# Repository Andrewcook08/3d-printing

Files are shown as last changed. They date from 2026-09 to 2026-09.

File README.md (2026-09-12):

# 3d-printing

Parametric 3D-printable parts, written as Python and exported as STL. Geometry
is built with [manifold3d](https://github.com/elalish/manifold); every project
writes its STLs into `output/<project>/`, ready to drop into a slicer.

**[How it works](docs/README.md)** — a map of the system: how parts are
generated, what the checks guarantee, and how the automation fits together.

## Projects

| Project | What it is |
|---|---|
| [`fishing-rod-mounts`](src/printing3d/fishing_rod_mounts/README.md) | Low-profile wall mounts for horizontal fishing rod storage |

Adding one? See the [project contract](docs/build/project-contract.md) — a
project is discovered by declaring itself, and inherits building, locking and
verification without writing test code.

## Getting started

You need [uv](https://docs.astral.sh/uv/). Everything else is handled for you:

```sh
uv sync
```

## Generating parts

```sh
uv run build                     # every project
uv run build fishing-rod-mounts  # just one
```

STLs land in `output/<project>/` and are committed, so you can print straight
from the repo without generating anything.

## Before you print

```sh
uv run verify
```

This measures the generated solids — not the parameters they came from — and
reports whether each part is physically sound. Each project defines its own
checks.

## Development

`main` is protected: it takes no direct pushes. Every change goes through a
branch and a pull request, and CI must pass before the PR can merge. No
reviewer approval is required, so you can merge your own work once it is green.

```sh
git switch -c fix/tip-mount-lip     # branch as <type>/<description>
# ...work, commit...
git push -u origin fix/tip-mount-lip
gh pr create --fill
gh pr merge --squash --auto         # merges itself once CI is green
```

Branch names are `<type>/<short-description>`, kebab-case:

| Type | For |
|---|---|
| `part/` | A new 3D-printing project |
| `feat/` | New capability in an existing project or the shared code |
| `fix/` | Correcting something that is wrong |
| `refactor/` | Restructuring with no change to any STL |
| `docs/` | Documentation only |
| `test/` | Tests only |
| `chore/` | Dependencies, tooling, CI |

The local checks:

```sh
uv run pytest              # tests
uv run ruff check --fix .  # lint
uv run ruff format .       # format
uv run ty check            # type check
```

In a fresh clone, install the git hooks once:

```sh
uvx pre-commit install
```

They run ruff, a few file-hygiene checks, and the test suite before each
commit. If a hook reformats a file the commit stops and the fix is left
unstaged — `git add` and commit again. Use `git commit --no-verify` to skip
them for a one-off, or `uvx pre-commit uninstall` to remove them.

Every project hash-locks its shipped STLs in a `LOCKED.txt`, and the test suite
rebuilds the parts and compares. A failure there means the exported shape
changed — see [CLAUDE.md](CLAUDE.md) for what to do about it, and for how to
add a new project.

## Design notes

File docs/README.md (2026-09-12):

# How this project works

This repo turns Python into printable parts. Each 3D-printing project describes
its parts parametrically; one command generates them as STL files into a shared
output location, and a layer of checks makes sure a change to the code cannot
silently change the parts.

The shape of it:

```
a project declares named parts
        │
        ├─ build ──▶ output/<project>/*.stl        the printable artifacts
        │
        ├─ verify ─▶ measurements of the solids    is it physically sound?
        │
        └─ tests ──▶ pass / fail                   did anything change?
```

Three properties hold the whole thing together:

- **Generation is deterministic.** The same source always produces the same
  bytes, which is what makes the parts hash-lockable.
- **Dimensions are derived, never restated.** A measurement is entered once;
  everything geometric follows from it.
- **Nothing reaches the default branch unchecked.**
- **Projects are found, not listed.** Adding one touches only its own files,
  and enrols it in every check automatically.

## The components

### Making parts

| Doc | Covers |
|---|---|
| [Project contract](build/project-contract.md) | What a project must declare, and what it inherits for free |
| [Build pipeline](build/pipeline.md) | A declared part becoming an STL file, and what building reports |
| [Geometry model](build/geometry.md) | How a part's shape is expressed, and why it prints without supports |
| [Output and locking](build/output.md) | Where files land, determinism, and the hash lock |

### Checking them

| Doc | Covers |
|---|---|
| [Testing strategy](quality/testing.md) | The test layers, and what a given failure pattern means |
| [Pre-print verification](quality/verification.md) | What the physical checks guarantee about a part |

### Automation

| Doc | Covers |
|---|---|
| [CI pipeline](automation/ci.md) | The gates on a change, and why they are shaped this way |
| [Dependencies](automation/dependencies.md) | Constraints versus pins, and the upgrade lifecycle |

## Where to start

Reading in order — [build pipeline](build/pipeline.md),
[output and locking](build/output.md), [testing](quality/testing.md) — explains
how a part is produced and why you can trust the file in `output/`. The rest can
wait until you need it.

For **using** the tool, see the [root README](../README.md). For **printing and
hanging** a specific part, see that project's own README next to its source.

## About these docs

They describe behavior, not implementation, so they stay correct across
refactors. They change only when the system's behavior changes. Before editing
any of them, use the `maintaining-docs` skill.

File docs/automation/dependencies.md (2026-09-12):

# Dependencies

How versions are controlled, and how an upgrade is evaluated before it lands.

## What it does

Two layers, deliberately separate:

| Layer | Holds | Answers |
|---|---|---|
| Constraints | Acceptable version ranges | What is *allowed* |
| Lock | One exact version per package | What is *installed* |

Automated builds install strictly from the lock. That makes them **hermetic**:
a new release of anything has no effect until the lock is deliberately moved.
This is what makes generated parts reproducible — and it means the normal
checks can never notice that a newer version exists.

Both layers are generated. Neither is edited by hand.

## Covering the gap

Because the checks are blind to new releases, two mechanisms watch from outside:

| Mechanism | Produces | Covers |
|---|---|---|
| Update bot | A pull request | Anything needing a decision *and* a commit, including the versions of the automation itself |
| Scheduled upgrade check | A report only | The case the bot misses — a new release that already satisfies an existing range, so no pull request is ever opened |

Neither names any package. Both derive the list from the declared constraints,
so a newly added dependency is covered the moment it is added.

The scheduled check resolves the newest allowed versions, runs every gate, and
**commits nothing**. Bot pull requests go through the ordinary gates, so an
upgrade that changes a part fails the hash lock and cannot merge.

## Guarantees

- An upgrade cannot land without passing every gate.
- An upgrade that changes any generated part is blocked until someone decides.
- A deprecation warning from a dependency fails the run, surfacing a future
  removal while there is still time to act.

## Reading a red upgrade check

**It is a decision, not a build to fix.** The failing gate names the category —
see [testing](../quality/testing.md) for the full table, but in short: parts
changed, code style changed, or a warning arrived.

Then choose, in a pull request:

- **Accept** — move the lock, re-lock anything whose bytes changed, and state
  in the request what changed and why it is acceptable.
- **Hold** — tighten the constraint so the new version is excluded, with a
  comment giving the reason.

Never re-lock a part purely to get to green. See
[output and locking](../build/output.md).

## How it fails

| Symptom | Meaning |
|---|---|
| Upgrade check red on the parts gate | A newer version would change the printed output |
| Upgrade check red on style or types | A newer tool is stricter or restyles code |
| A bot request cannot merge | It is behind the default branch, or a gate is red |
| Nothing happens for a long time | Expected — a hermetic build is quiet by design |

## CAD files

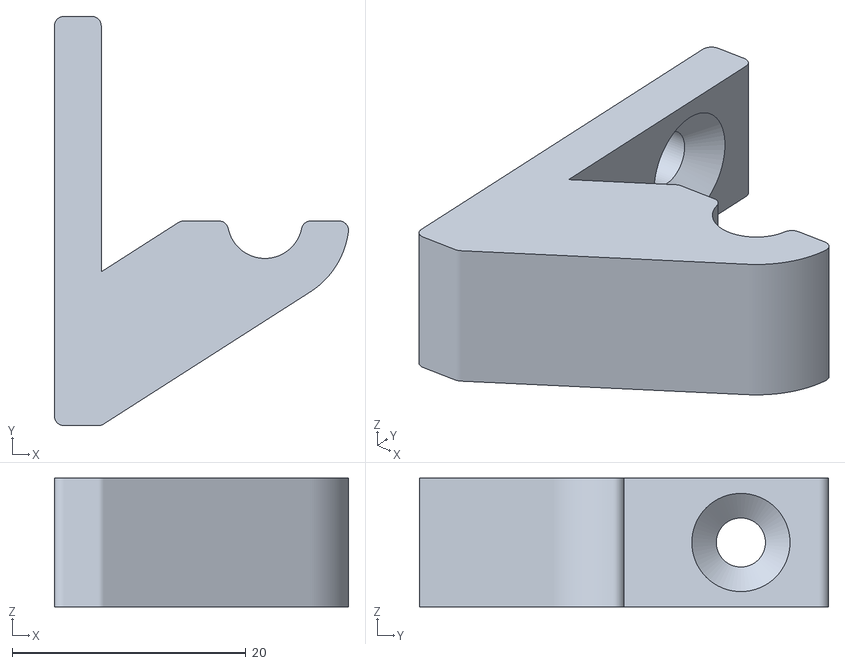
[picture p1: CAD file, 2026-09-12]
output/fishing-rod-mounts/spinning-85in-tip-5.80mm-v3.stl
25.1 x 35.0 x 11.0

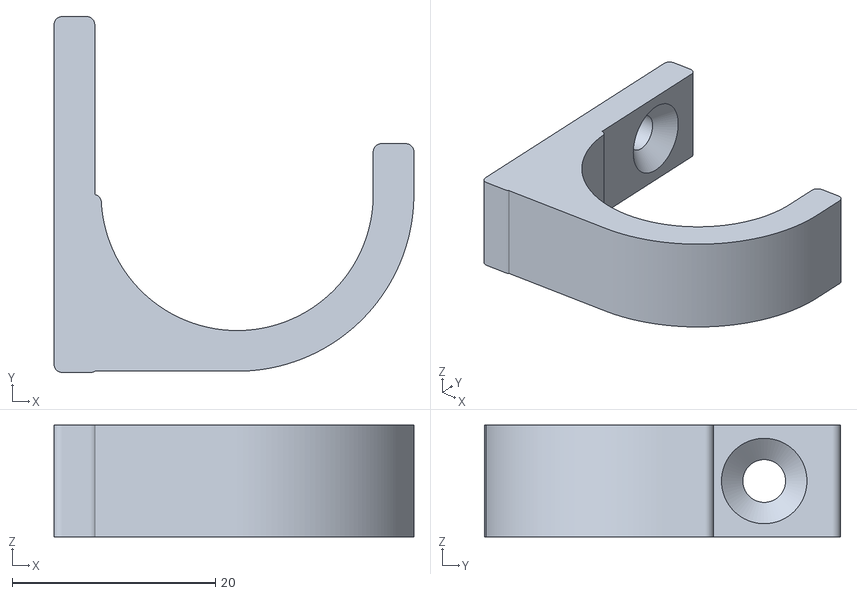
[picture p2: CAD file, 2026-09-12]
output/fishing-rod-mounts/spinning-85in-butt-26.15mm-v3.stl
35.4 x 35.0 x 11.0

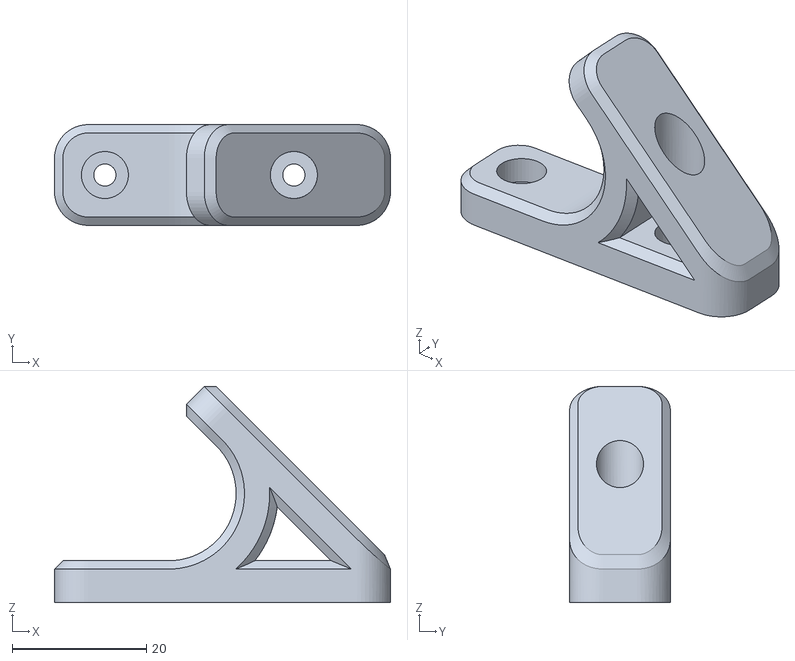
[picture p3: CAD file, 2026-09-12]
src/printing3d/fishing_rod_mounts/reference/wall_hook_for_3mm_screw(2).stl
50.0 x 15.0 x 32.2

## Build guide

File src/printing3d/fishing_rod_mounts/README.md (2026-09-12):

# Low-profile floating fishing rod mounts

Wall mounts that hold a rod horizontally with as little visible hardware as
physically possible. Two per rod: a thin curved rib that wraps the grip, and a
smaller one carried out from the wall on a tapered wedge for the blank.

Shape follows `reference/wall_hook_for_3mm_screw(2).stl` — thin plate, curved rib,
triangular gusset — rebuilt parametrically rather than scaled.

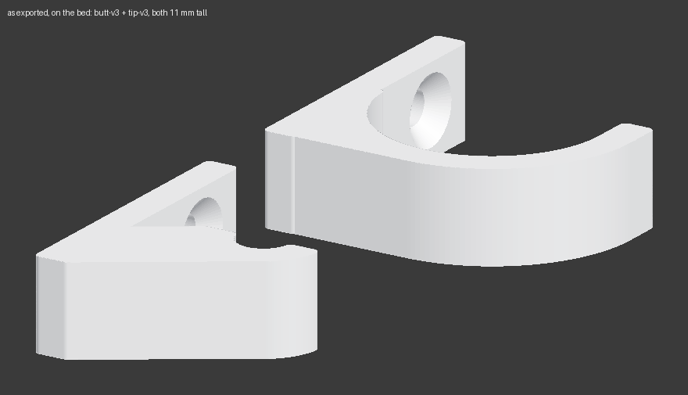
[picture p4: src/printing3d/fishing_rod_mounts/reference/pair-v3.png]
the pair


## Print these

One pair per rod. They share a 35 mm backplate, one screw hole at the same
height, and the same 11 mm slab thickness, so the two read as a set on the
wall.

| File | Size | Volume | Screws |
|---|---|---|---|
| **`output/fishing-rod-mounts/spinning-85in-butt-26.15mm-v3.stl`** | 35.4 × 35 × 11 mm | 3.9 cm³ | 1 |
| **`output/fishing-rod-mounts/spinning-85in-tip-5.80mm-v3.stl`** | 25.1 × 35 × 11 mm | 3.6 cm³ | 1 |

The butt mount is 35.4 mm deep against the tip's 25.1 mm, and that gap cannot
close: it is the 26.15 mm grip plus wall clearance plus the retaining rib.
Every other dimension now matches.

The tip mount's saddle and the wedge beneath it are both angled at **32.60°**.
That angle is forced, not chosen: the upper line must reach the top of the
cradle's wall-side wall and the lower one starts at the backplate's bottom
corner, so parallel + tangent to the crescent determines it.

### Slicer settings

Drop them into Bambu Studio and **do not rotate them.** They are exported
already lying in the correct orientation, which matters more than usual: the
part is a 2D profile extruded sideways, so this way it has zero overhangs — no
supports, nothing to clean out of the cradle — *and* the layer lines run across
the cantilever instead of along the plane the rod's weight would try to split.
Standing it upright would print worse and break easier.

- **PETG** preferred, PLA acceptable. PLA creeps under sustained load; at these
  stresses it will survive, but PETG is better for something loaded constantly.
- 0.2 mm layer height
- **4 wall loops** — the load is carried by the walls, not the infill
- 30 % infill, no supports, no brim needed

## Hang them

**Rotate each rod so the reel and guides point downward.** On both spinning and
casting rods the guides sit on the same side as the reel, so this is what puts
bare blank against the wall and lets the mounts stay close. The reel's weight
also self-rotates the rod into that position once it's in the cradle.

Both mounts share an **identical backplate** — same height, same screw holes,
same cradle-center height. So:

1. Mark a level horizontal line where you want the **bottom edge** of both
   mounts. Bottom edges aligned = rod level and parallel to the wall. There is
   no angle to work out at install time.
2. The screw hole sits **27.5 mm above that line**, centered.
3. Butt mount at the spot on the grip you measured; tip mount roughly 1440 mm
   further along (⅔ of the 85″ rod).
4. Leave **at least 150 mm of clear wall below** the line — the spinning reel
   hangs 133 mm below the rod.
5. #6 or #8 × 1¼″ flat-head screws into drywall anchors. Countersinks are on
   the front face so the heads finish flush.

With one screw you have to hold each mount level while you tighten it. Once
tight it stays put: the hanging rod applies roughly 96 N·mm of twist about the
screw, and friction between the plate and the wall under a tightened screw
resists that by more than an order of magnitude.

The back face is a flat unbroken pad, so double-sided tape works for a trial
hang before you commit to drilling. Clean the wall with alcohol first.

Optional: a scrap of adhesive felt in the cradle protects the grip finish.

## Changing the numbers

Everything derives from two measurements per rod. Edit `RODS` at the top of
`catalog.py`:

```python
RODS = [
    Rod(name="spinning-85in", butt_dia=26.15, tip_dia=5.80),
    Rod(name="baitcaster", butt_dia=00.00, tip_dia=0.00),
]
```

Then, from the repo root:

```sh
uv run build fishing-rod-mounts   # regenerate STLs into output/
uv run verify                     # check geometry before printing
uv run pytest                     # check the code
```

`uv run verify` is worth running after any change. It checks the things that
are easy to break and hard to spot: that the rod still lifts straight out, that
it is trapped sideways in both directions, that the screw bores are open and
countersunk on the front only, and that both mounts still seat the rod
centerline at the same height (17.22 mm in both, measured off the actual solids
rather than read back from the parameters).

The test suite covers the code rather than the physics. Its centerpiece is a
golden master: `LOCKED.txt` holds the sha256 of both shipped STLs, the
generator is deterministic, and the suite rebuilds the pair and compares.
Anything that moves a single vertex fails immediately — so if you are changing
the *shape* on purpose, expect that test to fail, and re-lock with:

```sh
shasum -a 256 output/fishing-rod-mounts/*.stl \
    > src/printing3d/fishing_rod_mounts/LOCKED.txt
```

### The files

| File | What lives there |
|---|---|
| `__init__.py` | Declares this project so the repo discovers it |
| `catalog.py` | The rods, the two mount styles, and what gets printed |
| `geometry.py` | The parametric shape: the cradle, the supports, the profile |
| `verify.py` | Geometric checks against the built solids |
| `LOCKED.txt` | Hashes of the STLs this project has shipped |
| `reference/` | The original wall hook the shape follows, and a photo of the pair |

Everything else is shared and lives one level up: 2D construction, solid
probing, the check runner, STL writing and output paths. Building, locking and
verification are covered by the repo-wide contract, so this project writes no
test boilerplate of its own — see
[docs/build/project-contract.md](../../../docs/build/project-contract.md).

## How it works

Parameterized on the **rod's centerline**, not on the standoff. `AXIS_U = 18.0`
puts the centerline 18 mm from the wall in *both* mounts; each cradle's depth
is whatever it takes to get there.

| | butt | tip |
|---|---|---|
| rod diameter | 26.15 mm | 5.80 mm |
| material between wall and rod | 4.62 mm | 14.80 mm |
| projection from wall | 35.38 mm | 25.20 mm |

That 4.6 → 14.8 mm difference is the extra offset the tip mount needs so the
handle doesn't sit further out than the tip. It's derived, not eyeballed.

Three constraints shape the rest:

**The plate can't be thicker than 4 mm.** The rod is a long cylinder, so it
can't dodge an obstruction — anything above the cradle sitting further from the
wall than the rod's near surface blocks it from lifting out, anywhere along its
length. `AXIS_U` is set so a uniform 4 mm plate clears the rod by ~0.9 mm,
which is also just enough to countersink a flat head properly.

**The screws have to be above the rod.** A weight hanging out from the wall
always tries to peel the *top* of the plate off, pivoting about the bottom
edge. Screws below the load would be in compression and do nothing.

**Projection is set by the rod, not the mount.** 35.4 mm at the butt is a
26.15 mm grip plus wall clearance plus a 4 mm retaining rib — there is very
little fat left to remove. What the rib-and-gusset structure buys is visual
lightness and material: 32 % less than a solid cradle on the butt mount, 50 %
less on the tip.

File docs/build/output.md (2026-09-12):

# Output and locking

Where generated files land, and how they are held to a known state.

## What it does

Every project writes its STLs to a shared output location, one directory per
project:

```
output/<project>/<part-name>.stl
```

These files are **committed**. You can print straight from a clone without
generating anything first.

## Redirecting the output

Setting `PRINTING3D_OUTPUT` replaces the root that projects write beneath.
Projects still get their own subdirectory under it. This is how tests and
experiments generate parts without touching the committed ones.

## Guarantees

**Determinism.** The same source produces byte-identical files on every run,
on any machine. That is not incidental — it is the property everything below
depends on.

Because the lock is written on a developer's machine and re-checked by
automation running a different operating system, a passing check is also
evidence of that "on any machine" claim: the two would disagree the moment the
output became platform-dependent.

**Each project is hash-locked.** A project keeps a `LOCKED.txt` recording the
sha256 of every STL it has shipped. The test suite regenerates the parts and
compares. Anything that moves a single vertex fails immediately.

**The committed files match the lock.** The STLs sitting in the output
directory are the ones the lock describes, so printing from the repo without
regenerating is safe.

## Contract

| | |
|---|---|
| Output root | `output/`, or `PRINTING3D_OUTPUT` when set |
| Per project | One subdirectory named for the project |
| Lock file | One per project, listing sha256 per shipped file |
| Written by | The build command only — never by hand |

## Re-locking

A lock mismatch means **the exported shape changed**. That is a decision, not a
build error:

- If the change was **unintentional**, fix the cause. Never re-lock to get to
  green.
- If it was **intentional**, regenerate, update the lock, and say in the pull
  request what changed about the shape and why that is acceptable.

A locked part that has already been printed is a physical object someone owns.
Changing its bytes silently means the next print no longer matches it.

## How it fails

The checks that assert *relationships* are the discriminator: while those pass,
the design is still correct however much the bytes moved.

| Symptom | Meaning |
|---|---|
| Hash mismatch, everything else passing | Something below the geometry changed how the solid is meshed. The design is untouched. |
| Hash mismatch, the pinned outline also failing, relationships still holding | The outline's vertices moved but the design holds — typically a change in how finely curves are divided, or an intended reshape. |
| Hash mismatch, a relationship failing | The design itself is wrong. Investigate before accepting anything. |
| A locked file is missing | The output was never generated, or was redirected. |

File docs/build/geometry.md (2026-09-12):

# Geometry model

How a part's shape is expressed, and the properties that fall out of it.

## What it does

A part is described as a **two-dimensional cross-section, extruded sideways**,
with fastener holes cut afterwards. The whole shape is therefore decided in a
flat profile before it ever becomes a solid.

## Why that shape

The extrusion direction is the print orientation, and it buys three things at
once:

- **No overhangs.** Every face is either vertical or horizontal in the print,
  so no supports are needed and nothing has to be cleaned out of an interior.
- **Layer lines across the load.** The layers run across the direction a load
  would try to split the part, not along it.
- **Exported ready to print.** Files come out already lying in that
  orientation. Rotating them in a slicer undoes both benefits.

## Guarantees

**Measurements are entered once.** A part is parameterised on what it holds —
its measured size — and every other dimension derives from that. Two parts
built for very different sizes still position what they hold identically,
because they share the same anchor points rather than each being tuned.

**Forced angles are computed, not chosen.** Where geometry fully determines an
angle — a face that must be tangent to a curve while staying parallel to
another — it is solved for. No such value is typed in as a number, so it stays
correct when a measurement changes.

**Interchangeable support structures.** How a part is carried out from its
mounting surface varies with the situation, and the alternatives are
substitutable. Which one a part uses is part of its declaration, not a branch
in the shape logic.

**The held object's space is subtracted last.** The clearance it needs, and the
channel it travels through to come out, are removed after everything else is
assembled. So they are correct no matter what was added above them, rather than
depending on every added piece having been careful.

## Contract

| | |
|---|---|
| Input | The measured size of what the part holds, plus its style |
| Output | A solid, ready to export |
| Invariant | Same input, same solid, every time |

## How it fails

A shape that cannot be built usually shows up as an **unsound solid** — not
watertight, or in more than one piece — which the build reports and refuses to
pass. Shapes that build cleanly but are physically wrong are caught separately,
by [pre-print verification](../quality/verification.md).

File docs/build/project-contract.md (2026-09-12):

# Project contract

What a 3D-printing project must provide, and what it gets in return.

## What it does

A project declares itself inside its own package. Nothing central lists the
projects — they are found by looking, so adding one touches only that project's
own files and never a file shared with every other project.

## What a project must declare

| Declares | Meaning |
|---|---|
| A name | Kebab-case. Names its output directory and its command-line argument. |
| A summary | One line, shown in the command-line help. |
| Its parts | What it ships: each a name and a solid. |
| How to build | Writes those parts to its output directory. |
| How to verify | Its physical checks. **Required** — see below. |
| A lock | The file recording the hash of everything it has shipped. |

Identity is available without loading any geometry, so listing the projects
stays cheap however many there are. The heavier parts load only when something
asks for them.

## Guarantees

**Declaring a project enrols it in everything.** It is built by the build
command, checked by the verify command, and covered by the shared conformance
tests, without writing any test code.

Those tests assert, for every project: that it declares all of the above; that
its part names are unique; that every locked file is still produced; that
rebuilt bytes match the lock; that the committed output matches the lock; that
every part is a single watertight body; that building writes exactly the
declared parts under the project's own name; and that its verification passes.

**Verification is not optional.** A project that cannot check its own parts
fails the contract. A part that reaches the output directory has been measured.

**The shared kit never depends on a project.** Shared code stays reusable only
while it carries no project's assumptions, so the direction of that dependency
is checked rather than trusted.

## What a project writes for itself

Only what is genuinely its own: the shape of its parts, the physical checks
that shape must pass, and tests for anything specific to it. Everything else is
inherited.

## How shared code grows

A helper starts inside the project that needs it. When a second project needs
the same thing, it moves into the shared kit unchanged. Only utilities with no
subject-matter knowledge are eligible — anything shaped around what a
particular project makes stays with that project, because generalising from a
single example means guessing what the second one needs.

## How it fails

| Symptom | Meaning |
|---|---|
| Contract tests fail for one project, named in the result | That project's declaration or output is wrong; the others are unaffected |
| A project is not built and not listed | It declares nothing discoverable |
| Failures mention the shared kit depending on a project | Shared code has acquired a project's assumptions and is no longer reusable |

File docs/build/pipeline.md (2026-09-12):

# Build pipeline

How a part that exists only as parameters becomes a file you can print.

## What it does

Each project declares a set of parts. A part is a name and a solid. Building
writes every declared part to that project's output directory as binary STL.

```sh
build                     # every project
build <project>           # one project
```

## Guarantees

- **Deterministic.** The same source produces byte-identical files on every
  run. Nothing about the output depends on when or where it ran.
- **Complete or loud.** Every declared part is written, or the command reports
  a problem and exits non-zero.
- **Self-describing files.** A part's name is both its filename and a label
  recorded inside the file, so a file separated from this repo still says what
  it is.

## Contract

| | |
|---|---|
| Input | The declared parts of one or more projects |
| Output | One STL per part, under the project's output directory |
| Also written | A report line per part, on standard output |
| Exit code | `0` if every part is sound, `1` otherwise |

Naming a project that does not exist is rejected, with the valid names listed.

Because the part's name is written into the file's contents, **renaming a part
changes its bytes** — and therefore its hash. That is not a quirk to work
around; it is why a file can be trusted to identify itself.

## What building reports

For each part: its overall dimensions, its volume, how many triangles it took,
and whether the solid is sound. A project may add a line of its own above each
part — a derived dimension worth seeing at build time, such as how far the part
will stand off the wall.

"Sound" means the solid is watertight, free of errors, and a single connected
body. An unsound solid is reported and the command fails, because a slicer
cannot be trusted to do something sensible with one.

## How it fails

| Symptom | Meaning |
|---|---|
| Exit `1`, a part marked as needing checking | The solid is not watertight or is in more than one piece. Do not print it. |
| Exit `2`, valid names listed | An unknown project was requested. |
| Files appear somewhere unexpected | The output location was redirected; see [output and locking](output.md). |

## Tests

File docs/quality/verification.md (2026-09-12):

# Pre-print verification

Physical checks on the generated solids. Run before printing.

```sh
verify
```

## What it does

Where the tests ask *"did anything change?"*, verification asks *"is this part
physically sound?"* — by measuring the finished solids and printing what it
measured, so the numbers are visible rather than merely asserted.

Crucially it measures the **solids**, not the parameters they came from. A
mistake anywhere between a dimension and the exported shape still shows up.

## Guarantees

For each part, that the object it holds:

- **Seats without interference** — it fits where it is supposed to sit.
- **Comes straight out** — nothing above the cradle blocks removal along the
  whole length of a long object that cannot dodge sideways.
- **Is trapped in both directions** — it can neither roll back toward the
  mounting surface nor forward out of the cradle.
- **Clears the mounting surface** — there is air between it and the wall.

For each fastener, that its hole is **open through the part** and
**countersunk on the front face only**, leaving the back a flat unbroken pad;
and that it sits clear of the cradle with enough material above it.

For a matched pair, that both parts **place what they hold at the same
height**, within a tolerance tight enough that a long object spans them without
a visible tilt.

Each project defines its own checks. These are the ones that are easy to break
and hard to spot by eye.

## Contract

| | |
|---|---|
| Input | The built solids, generated fresh |
| Output | One `PASS`/`FAIL` line per check, with the measured value |
| Exit code | `0` if every check passes, `1` otherwise |
| Side effects | None. It reads; it never writes a file. |

The same checks also run inside the test suite, so a part that fails them
cannot reach the default branch unnoticed.

## How it fails

A `FAIL` line names the check and shows the measurement that broke it — the
interference volume, the clearance, the height mismatch. Compare it against the
threshold in the same line to see how far out it is.

**A failure here means do not print.** The file may well be watertight and
perfectly exportable; it is the *part* that is wrong.

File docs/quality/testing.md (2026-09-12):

# Testing strategy

What the tests guarantee, and how to read a failure.

## What it does

Four layers, ordered by how precisely a failure points at its cause. When
something changes, the narrowest layer that noticed tells you what moved.

| Layer | Asserts | Catches |
|---|---|---|
| **Contract** | What every project must guarantee, for every project | A project that ships unverified, unlocked, or unsound parts |
| **Properties** | Relationships that must hold for *any* input | A design that is geometrically wrong, including for sizes never built before |
| **Characterization** | The exact vertices of each shipped cross-section | A change to a part's outline, naming which part moved |
| **Golden master** | The exact bytes of each shipped file | Any change at all to a printable artifact |
| **Command** | The installed commands behave like the library | Broken entry-point wiring that library tests cannot see |

## Guarantees

**The contract layer applies itself.** It runs over whatever projects exist, so
a new project is covered by existing rather than by copying tests, and a
failure names the project it belongs to. See
[project contract](../build/project-contract.md).

**Properties assert intent, not history.** Where a value is forced by geometry,
the test asserts the *relationship* — that a line is genuinely tangent to a
curve, that two parts place what they hold at the same height — rather than
pinning the number that relationship currently produces. Change a measurement
and these still hold.

**The golden master is an integration test.** It builds parts through the real
generation path and writes real files, so a dependency that breaks generation
fails here. It runs on every change, including automated dependency updates.

**Warnings are failures.** A dependency's deprecation warning fails the suite,
so a removal two releases away surfaces while there is still time to act.

**The commands are exercised as commands.** One test runs the installed
executables as subprocesses and compares their output to the library's. That
plus the golden master means the shipped command produces the locked bytes,
without either test needing to know about the other.

## What the tests cannot tell you

The golden master is a **change detector, not a correctness oracle**. It proves
the output did not change. It cannot prove a changed output is wrong, or that
an unchanged one is right — a design wrong from the start stays green forever.
Only the property layer asserts intent, and only for the relationships it
covers. Nothing here knows whether a part survives its load or fits the real
object.

## How to read a failure

| Pattern | Meaning |
|---|---|
| Properties pass, characterization passes, bytes differ | Meshing changed beneath the geometry. Design untouched. |
| Properties pass, characterization fails | A part's outline moved. Usually an intended design change. |
| Properties fail | The design itself is wrong. Investigate before anything else. |
| Command test alone fails | The library is fine; the installed entry point is broken. |
| Contract test fails, named for one project | That project's declaration or output is wrong; others are unaffected. |
| A deprecation warning fails the run | A dependency is signalling a future removal. |

## Where they run

Before each commit (via hooks), on every pull request, and in the scheduled
upgrade check described in [dependencies](../automation/dependencies.md).

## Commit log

2026-09-12 Set up as a uv Python project with the fishing rod mounts
    Restructure the repo so multiple 3D-printing projects can live side by side,
    each generating STLs into a shared output/ directory.
    - One package, src layout: printing3d, with a subpackage per project.
    Shared machinery is stl.py (binary STL) and parts.py (what a Part is and
    where its file lands); cli.py provides `build` and `verify`.
    - Tooling per the modern Python project setup guide: uv, ruff, ty, pytest,
    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
    [spinning-85in-butt-26.15mm-v3.stl, spinning-85in-tip-5.80mm-v3.stl, wall_hook_for_3mm_screw(2).stl]
2026-09-12 Document the branching and pull request workflow (#1)
    main is now protected: it rejects direct pushes, including from the repo
    owner, and requires a pull request with the `test` workflow passing. No
    reviewer approval is required, so you can merge your own green PR.
    Record the <type>/<description> branch convention in both places that need
    it: README for the human-facing flow, CLAUDE.md operationally, since an
    agent would otherwise try to commit straight to main.
    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
2026-09-12 Add Dependabot and a weekly manifold3d upgrade canary (#3)
    CI runs `uv sync --locked`, so it installs exactly what uv.lock pins and can
    never notice a new manifold3d release. That hermeticity is what makes the
    STLs reproducible, but it means dependency rot is invisible to every check
    currently in place.
    Two layers close that, for two different failure modes:
    - Dependabot opens weekly PRs. These go through the normal gate, so a bump
    that changes an STL fails the golden master and cannot merge. This covers
    the case where the lock moves.
    - The canary covers the case where it does not. Since the constraint is a
    range, a new release already satisfies pyproject.toml and Dependabot may
    o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
2026-09-12 Extract a reusable build kit and make the project contract executable (#8)
    Adding a project meant copying plumbing: the golden-master suite was ~52 lines
    of which only three imports were project-specific, three more catalog tests
    were equally generic, and the pure utilities a part needs lived inside the one
    project that happened to have them.
    The shared kit gains shapes (2D construction), probes (measuring built solids)
    and checks (the pass/fail runner) -- all verified body by body to contain no
    subject-matter concepts before moving. Geometry and verification now consume
    them, and the promoted code arrives with its own tests rather than only being
    exercised indirectly.
    Projects are discove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
2026-09-12 Say which check layer distinguishes a remesh from a design change (#10)
    The lock-failure table said "shape checks", which reads as either the
    relationship checks or the pinned outline. They can disagree: changing how
    finely a curve is divided moves the outline and the bytes while every
    relationship still holds, and the old wording pointed at "the geometry itself
    moved" -- the wrong conclusion.
    Found by deliberately simulating that case against the real gate.
    Claude-Session: https://claude.ai/code/session_01WfzPzwidjZs6zneDBnWRpd
2026-10-26 part(hue-tv-brackets): matching straight and corner clip brackets (#14)
    * part(hue-tv-brackets): add source meshes for the Hue TV bracket project
    Three STLs dropped into src/printing3d/, moved into the new project's
    reference/ folder where source meshes belong. No project declaration yet,
    so nothing is discovered or built.
    Claude-Session: https://claude.ai/code/session_01S2CuzNWz3gw7Fwtv2RwpLZ
    * feat: catch a helper that two projects both define
    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
